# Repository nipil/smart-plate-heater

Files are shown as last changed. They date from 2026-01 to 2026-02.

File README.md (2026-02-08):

# smart-plate-heater

A weight-based, smart plate heater for ease of use and safety

- The posh wooden plate that the user sees !

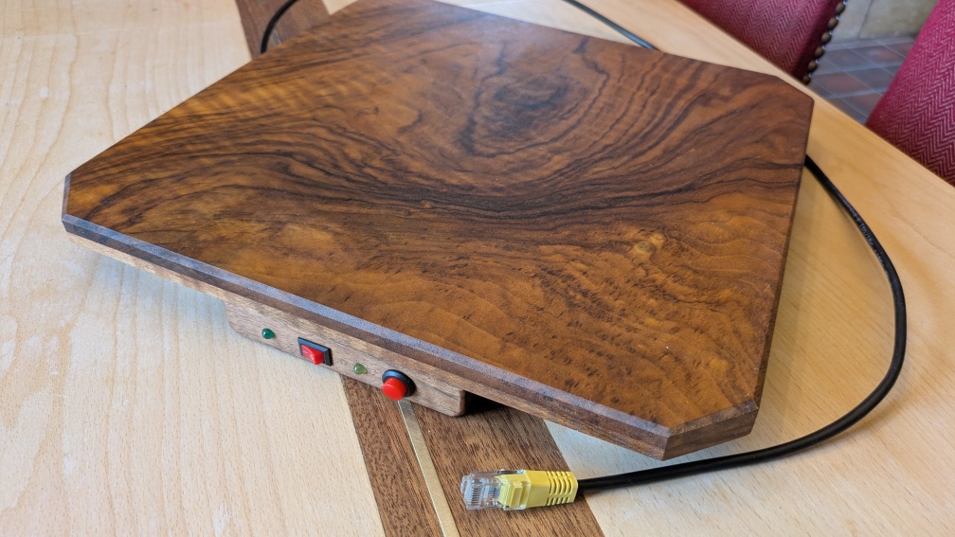
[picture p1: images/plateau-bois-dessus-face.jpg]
nice plateau


- The back "measuring foot"
  - holding all the wieght in a 3-points-of-contact setup
  - maximum 5kg vertically on the back, so an average of 10kg in center
  - the back feet do nothing except prevent tumbling

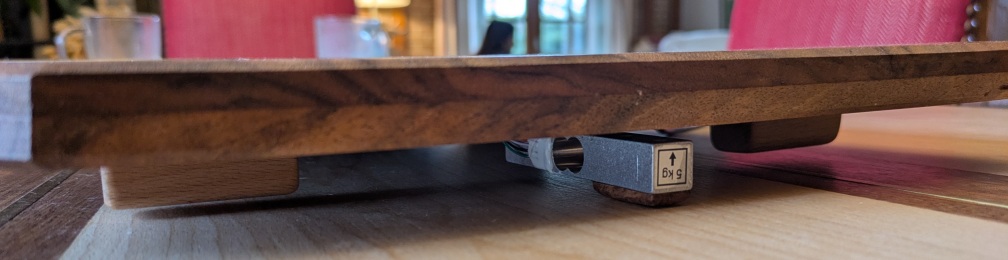
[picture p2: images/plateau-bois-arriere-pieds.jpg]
measuring foot


- due to the sensitivity of the voltages used for measuring using a strain gauge, the pre-processing must be done locally... plus the panel can be done locally too and everything fits in the 8 wires of the network cable

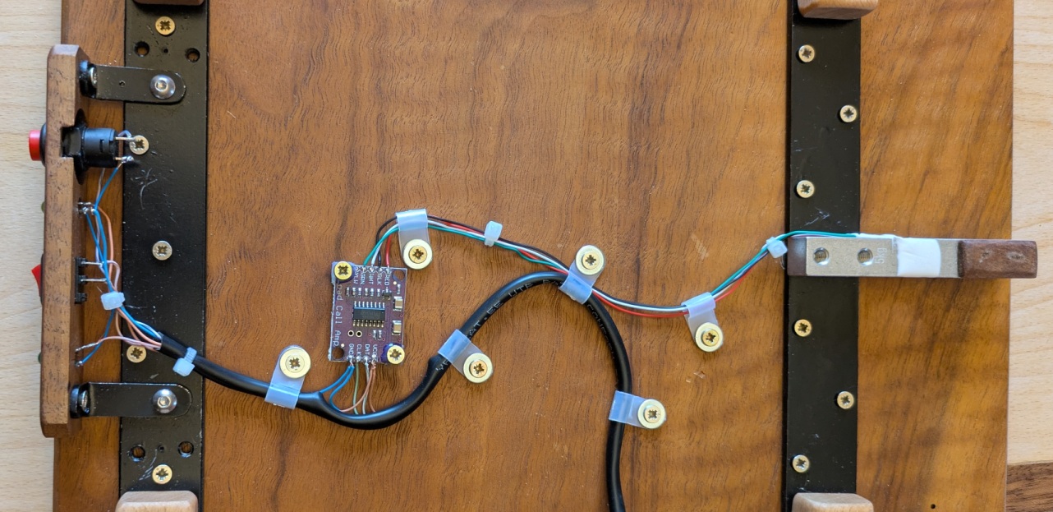
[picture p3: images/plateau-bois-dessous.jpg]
the innards


The target "perfboard pcb", with only 3 additional wires (solid core, 26 AWG, ptfe isolated wires)

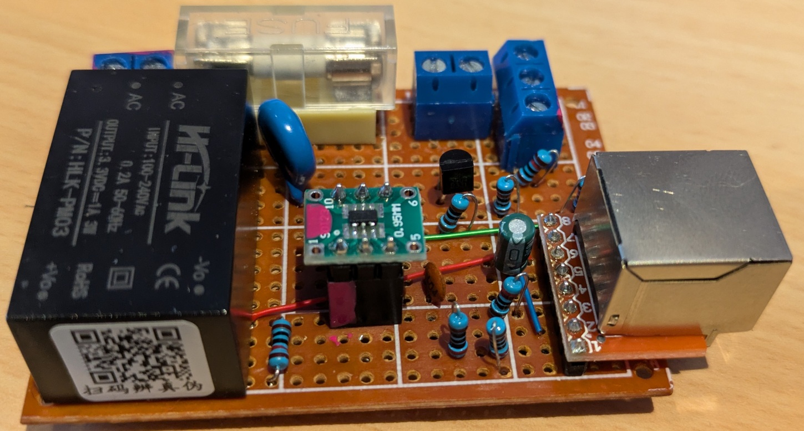
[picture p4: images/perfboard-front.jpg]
perfboard front


Only 3 shrink fit insulation patches, where i forgot to make multi-level "manhattan-style" routing

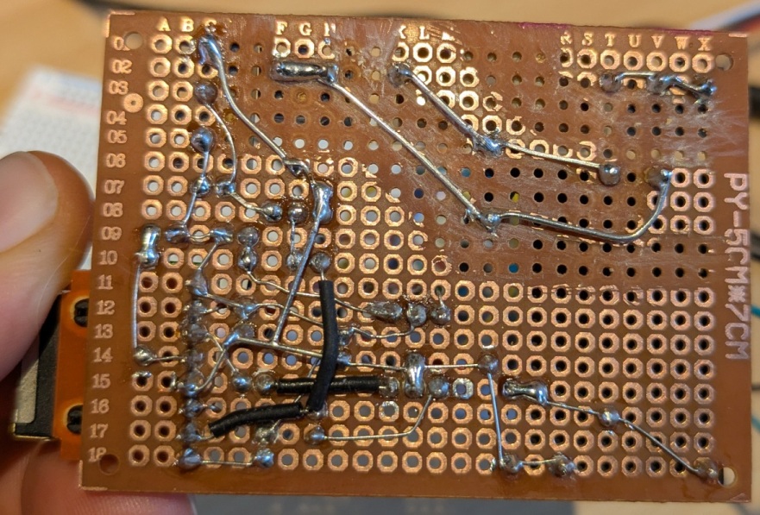
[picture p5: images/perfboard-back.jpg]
perfboard back


Everything fits in a 80x80 mm derivation box, even if it is crowded. And i can still easily take the microcontroller out, for in-situ calibration with another "debugging" MCU, and re-program the "target" MCU before sticking it back in.

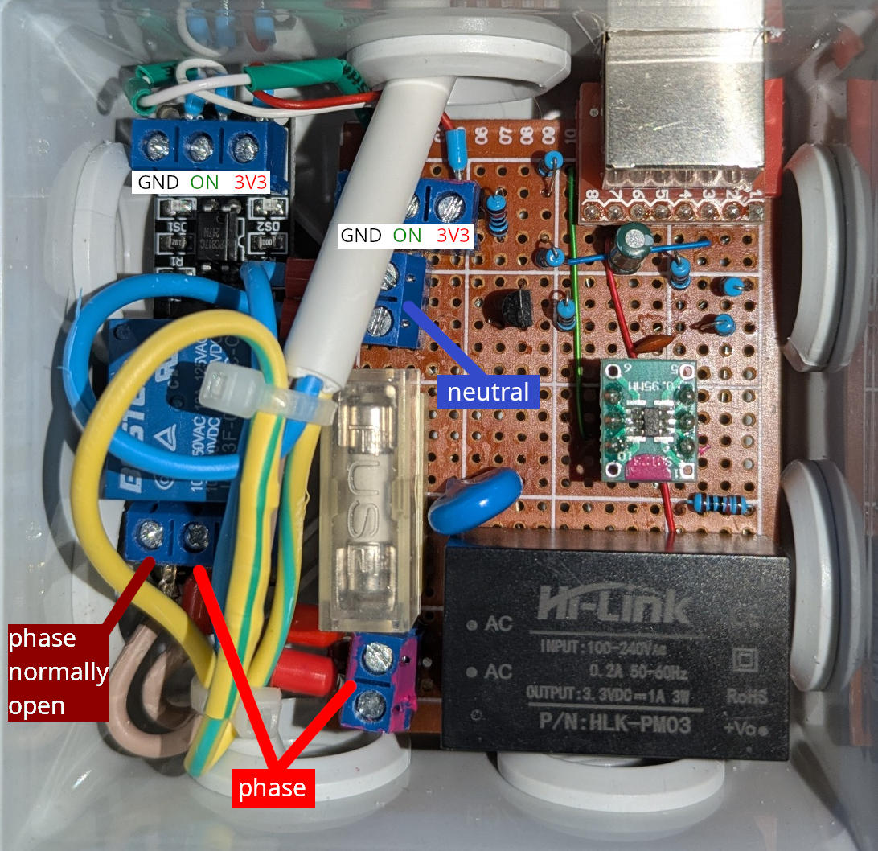
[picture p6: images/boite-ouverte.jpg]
box inside


Finally i managed to make both output exit on the same side, and the input on the opposite side, which is pretty neat.

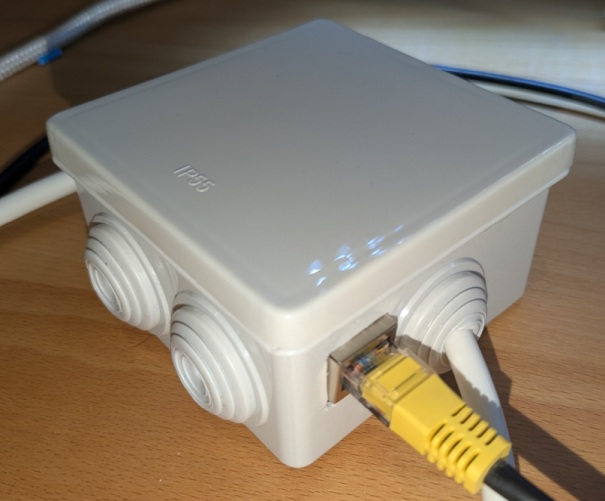
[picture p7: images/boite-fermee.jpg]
box outside


## Schematic and "perfboard" PCB

The way the main board works and AC safety is done in the derivation box

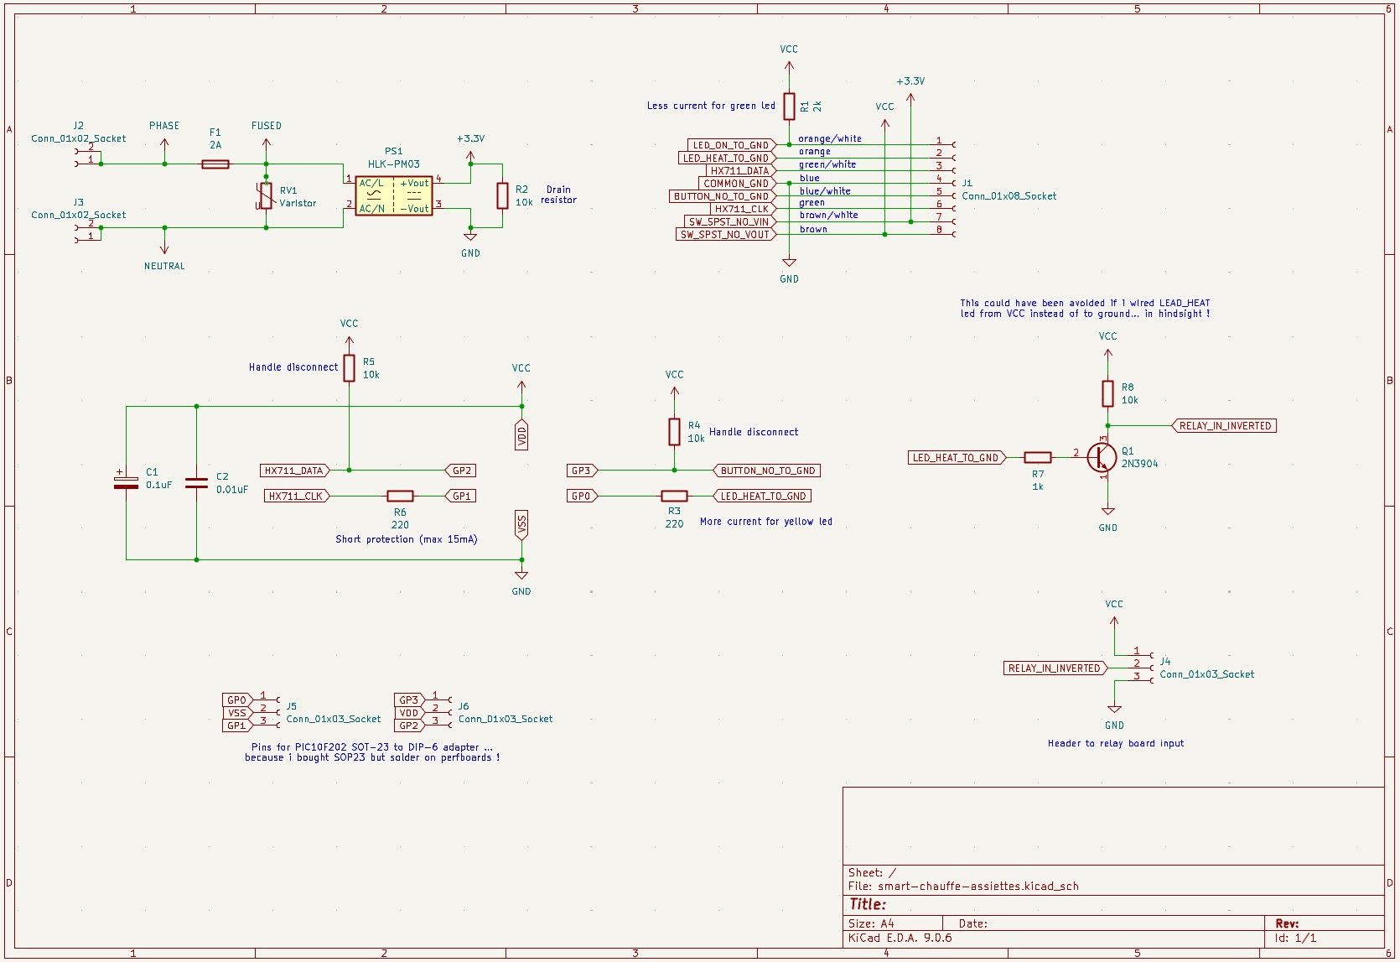
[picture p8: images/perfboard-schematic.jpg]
perfboard schematic


I always prepare my perfboard routing on a appropriately sized PCB

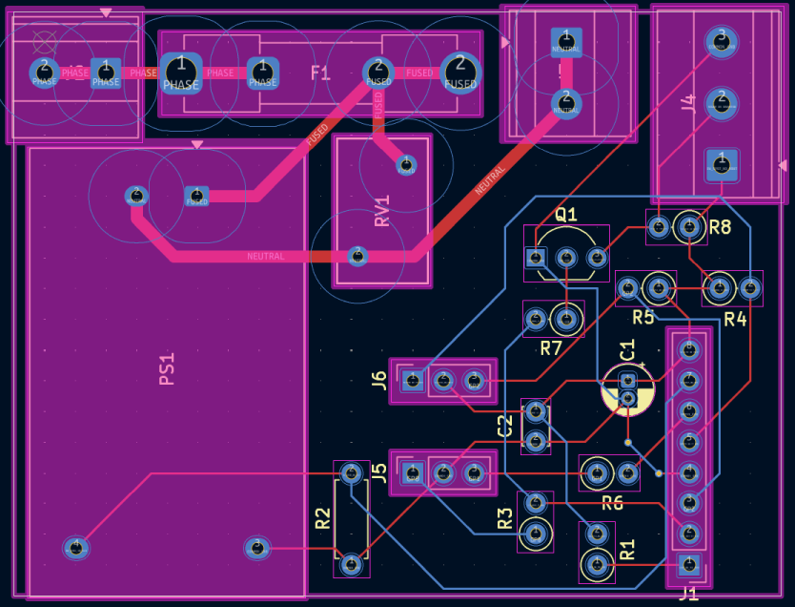
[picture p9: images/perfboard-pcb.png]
perfboard pcb


The way the appliance and user panel is wired

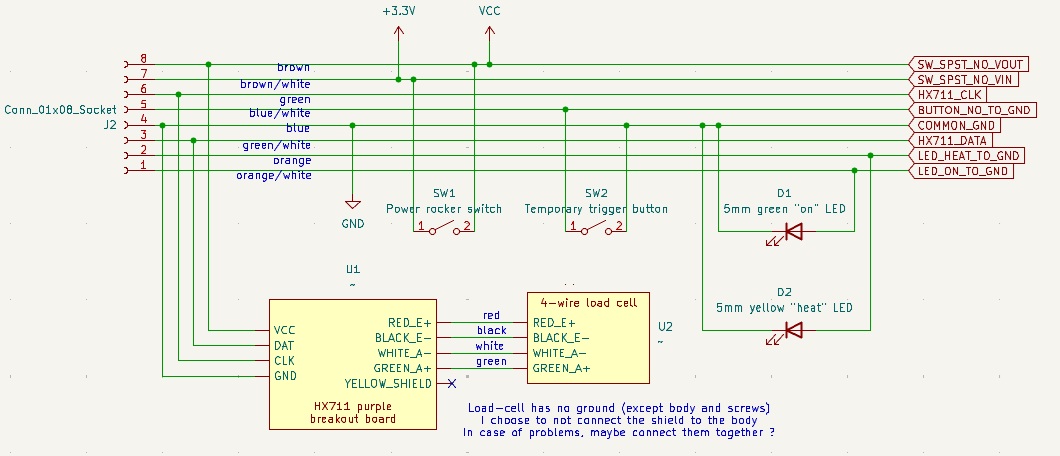
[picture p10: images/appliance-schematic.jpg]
appliance schematic


## Hardware

Target board on perfboard (uses 8mA@3V3 at idle and 80ma@3V3 when relay is on)

- PIC 10F200-family microcontroller (here a 202 in SOP-23 a DIP breakout board) from rs-online.com

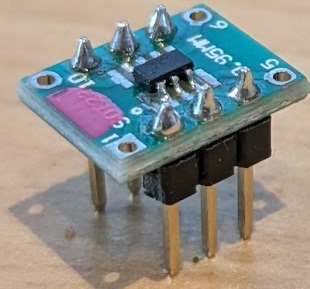
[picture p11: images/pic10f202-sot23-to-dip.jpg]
PIC 10F20x


- 500mA 5x20 fuse and fuse holder (oversized, the whole thing draws less than 0.35 W at full load)

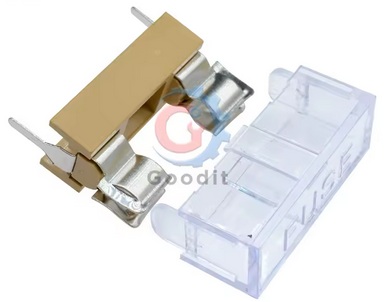
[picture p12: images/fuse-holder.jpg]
Fuse holder


- varistor 10D561K (transient voltage suppressor TVS) ot protect the circuit from grid surges

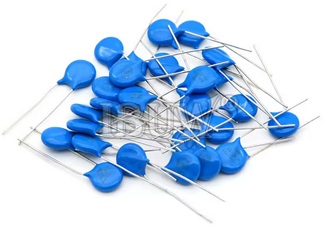
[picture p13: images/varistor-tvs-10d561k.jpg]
Varistor


- HLK-PM03 3W 240VAC to 3.3VDC converter (isolated)

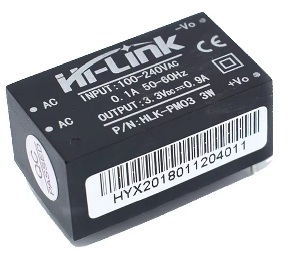
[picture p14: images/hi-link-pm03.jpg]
HLK-PM03 AC to DC converter


- HX711 breakout board (purple with holes for fixturing

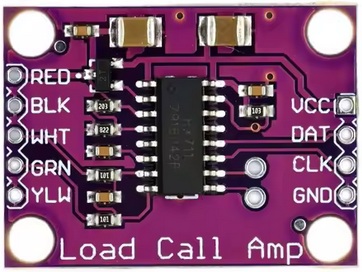
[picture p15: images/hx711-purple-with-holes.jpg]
HX711 differential ADC for strain gauges


- Beam-type load cell (maximum 5KG)

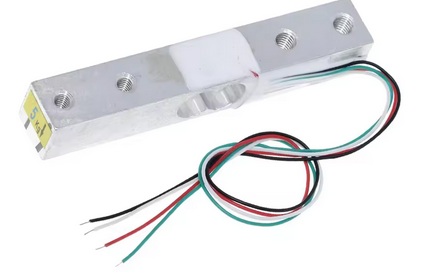
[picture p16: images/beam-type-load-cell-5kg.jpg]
Beam load cell 5KG


- 3.3V relay board (active low, floating high)

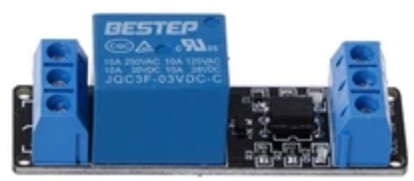
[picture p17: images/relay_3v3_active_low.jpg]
3.3V relay board


- network port breakout board, and a network cable to cut

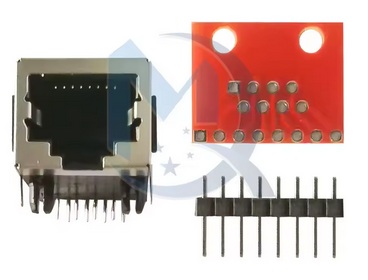
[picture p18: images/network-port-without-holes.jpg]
Network socket on a breakout board


- normally open temporary button, single pole single throw (SPST) rocker switch...
- screw terminals, 1/4W resistors, 5mm LED, headers,dc caps, 2N3904 NPN transitor...

For prototyping

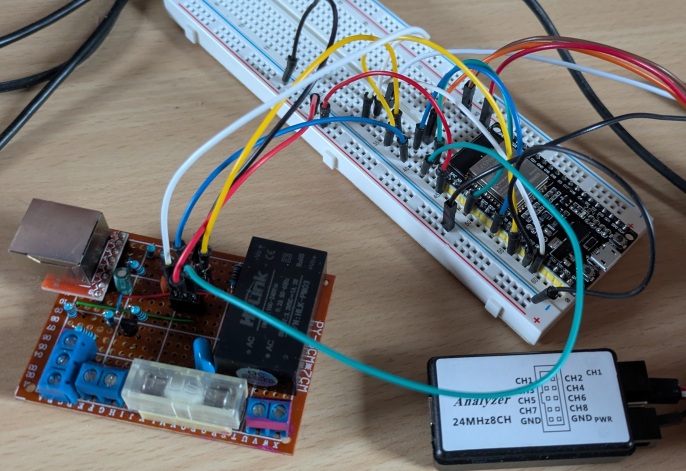
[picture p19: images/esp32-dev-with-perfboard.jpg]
dev prototyping


- breadboard and dupont cables
- ESP32 DevKit 38 pins

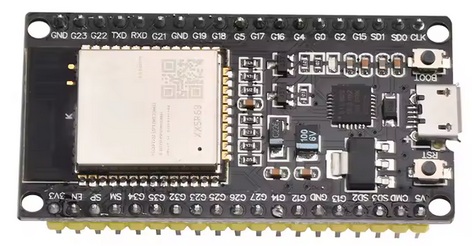
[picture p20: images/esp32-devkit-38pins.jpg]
ESP32 DevKit 38 pins


- logic analyzer (salae clone)

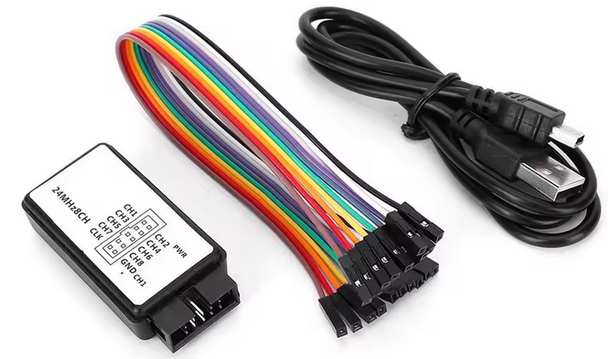
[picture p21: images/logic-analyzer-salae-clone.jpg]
Logic analyzer


Real wafeforms results in PulseView software from ESP prototype

- Macro waveforms to see sampling rate of HX711 breakout board (1 sample per 0.4 second = 2.5 Hz)

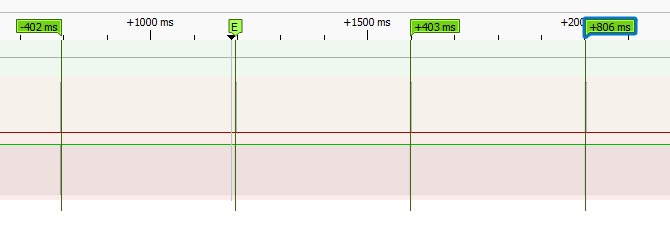
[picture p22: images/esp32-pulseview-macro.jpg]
waveforms macro view


- Micro waveforms to check the clock and data timings (data transfer time is 115 micro-seconds)

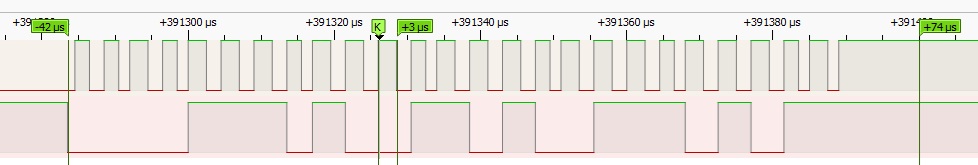
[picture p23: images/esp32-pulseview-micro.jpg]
waveforms micro view


## Pinouts

Using a PIC10F202 as microcontroller

Target perfboard using PIC10F202 SOT-23-to-DIP pinout

    PIN 1 = GP0 = OUT_HEAT  PIN 6 = GP3 = IN_BUTTON
    PIN 2 = VSS (-)         PIN 5 = VDD (+)
    PIN 3 = GP1 = OUT_CLK   PIN 4 = GP2 = IN_DATA

Arduino prototype on ESP32 DevKit pinout

    G14 = OUT_HEAT
    G25 = OUT_CLOCK
    G13 = IN_DATA
    G34 = IN_BUTTON

## kicad folder

Design for electronics and target solderboard in a box

## mplab.x folder

PIC IDE, and C code built with XC8 compiler to generate HEX file

- [Pre-compiled HEX file for a PIC10F202 microcontroller](mplab.X/pic10f202-production.hex)
- which you can program using my homemade [Arduino-UNO-based simple pic programmer](https://github.com/nipil/arduino-simple-pic-programmer)

### Debugging

Go to `Tools/Options/Embedded`

- debug reset `reset vector`
- debug startup `halt at reset vector`
- activate stimulus (*.scl) file
- use simulator to debug

### Chip fuses

Go to `Window/Target Memory View/Configuration bits`

- disable MCLRE to be able to use GP3

## arduino-esp-prototype-software folder

This is an archived folder for an arduino framework, ESP32-devboard-based prototype

Achieved goals :

- verify that everything works on 3.3V
- discover raw values for "empty" aparatus
- discover raw values for "edge" beam strain gage
- discover effect of the weight of the cable (!)
- discover the "one kilogram on center" desired threshold
- verify light / transistor / relay working when desired
- verify values upon cable disconnection
- verify disconnection disabling
- verify negative/zero HX711 values disabling
- verify reset conditions disabling
- verify heat triggering by button when above threshold
- verify heat disabling when going under threshold

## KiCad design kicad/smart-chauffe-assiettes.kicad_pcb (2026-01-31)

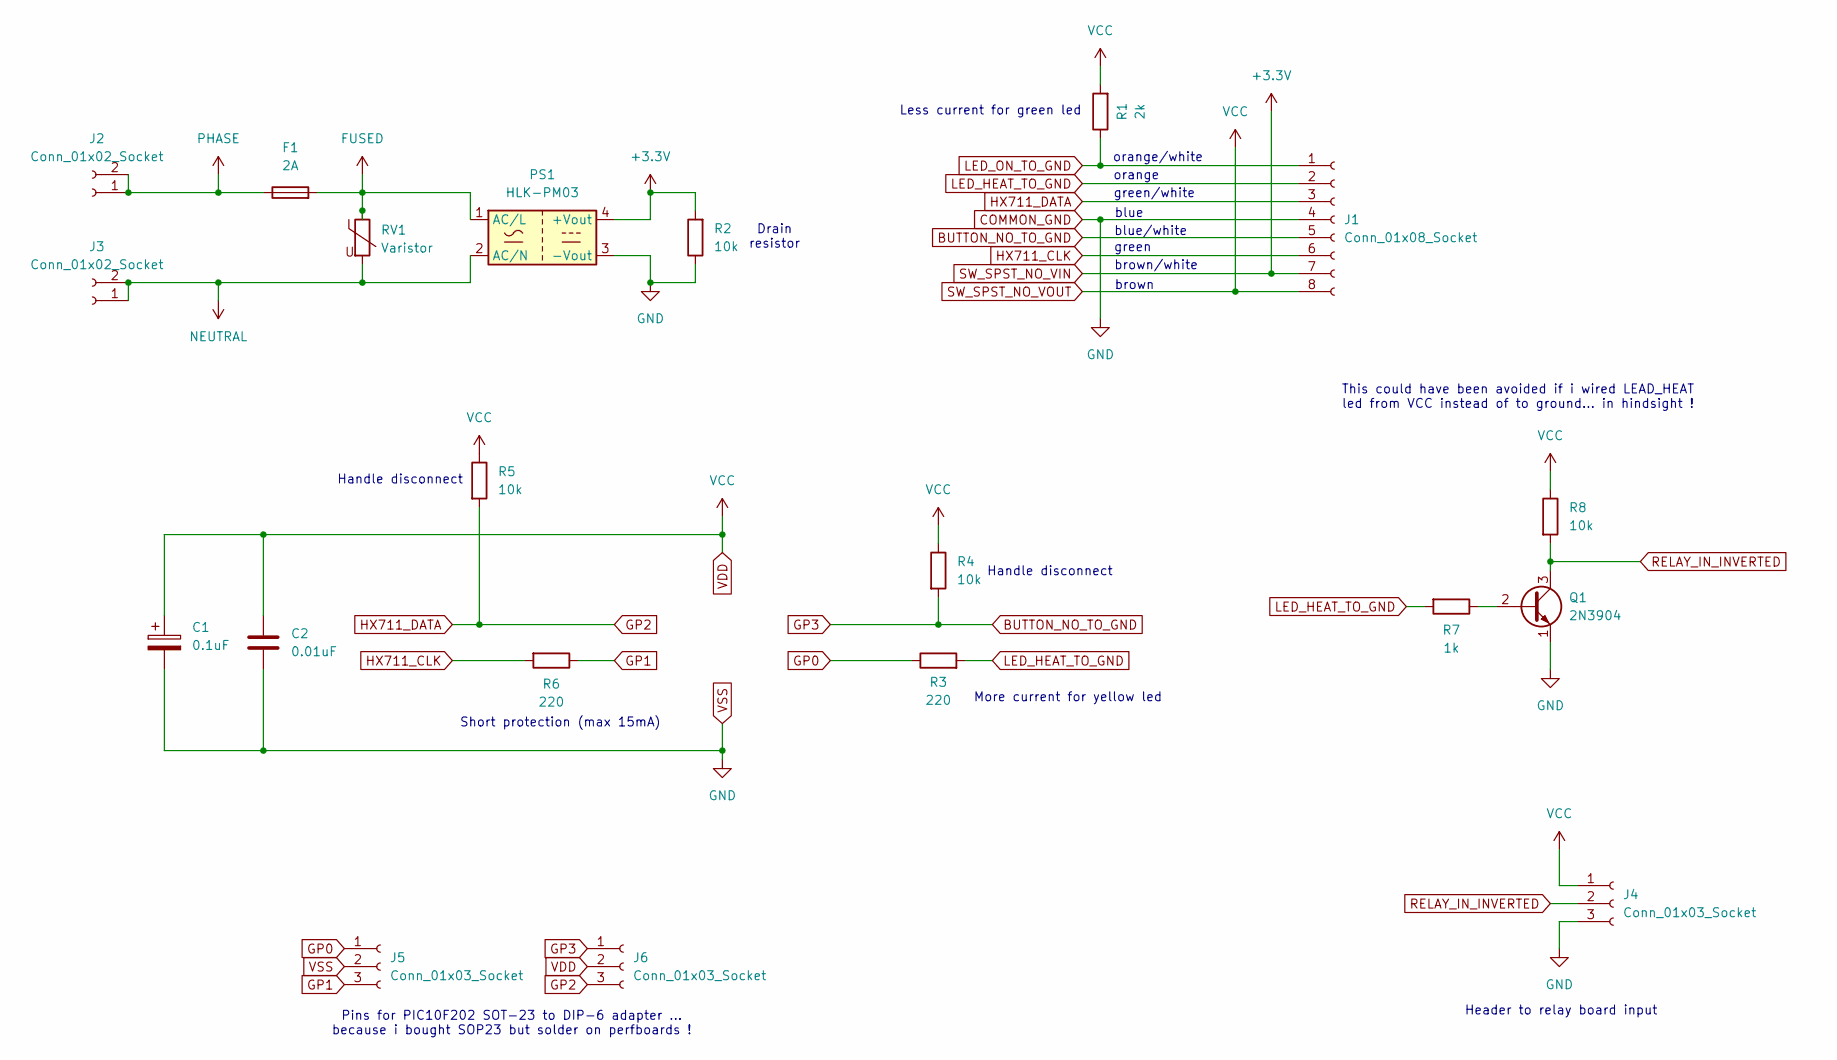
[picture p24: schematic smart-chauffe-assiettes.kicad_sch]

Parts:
C1: 0.1uF; CP_Radial_D4.0mm_P1.50mm
C2: 0.01uF; C_Disc_D3.0mm_W2.0mm_P2.50mm
F1: 2A; Fuseholder_Clip-5x20mm_Keystone_3518P_Inline_P23.11x6.76mm_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
J1: Conn_01x08_Socket; PinHeader_1x08_P2.54mm_Vertical
J2, J3: Conn_01x02_Socket; TerminalBlock_Phoenix_MKDS-1,5-2-5.08_1x02_P5.08mm_Horizont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
J4: Conn_01x03_Socket; TerminalBlock_Phoenix_MKDS-1,5-3-5.08_1x03_P5.08mm_Horizont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
J5, J6: Conn_01x03_Socket; PinSocket_1x03_P2.54mm_Vertical
PS1: HLK-PM03; Converter_ACDC_Hi-Link_HLK-PMxx
Q1: 2N3904; TO-92_Inline_Wide
R1: 2k; R_Axial_DIN0207_L6.3mm_D2.5mm_P2.54mm_Vertical
R2: 10k; R_Axial_DIN0207_L6.3mm_D2.5mm_P7.62mm_Horizontal
R3, R6: 220; R_Axial_DIN0207_L6.3mm_D2.5mm_P2.54mm_Vertical
R4, R5, R8: 10k; R_Axial_DIN0207_L6.3mm_D2.5mm_P2.54mm_Vertical
R7: 1k; R_Axial_DIN0207_L6.3mm_D2.5mm_P2.54mm_Vertical
RV1: Varistor; RV_Disc_D12mm_W7.5mm_P7.5mm

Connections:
BUTTON_NO_TO_GND: J1.5, J6.1, R4.2
COMMON_GND: C1.2, C2.2, J1.4, J4.3, J5.2, PS1.3 (-Vout), Q1.1 (E), R2.1
FUSED: F1.2, PS1.1 (AC/L), RV1.1
GP0: J5.1, R3.1
GP1: J5.3, R6.1
GP2: J1.3, J6.3, R5.2
HX711_CLK: J1.6, R6.2
LED_HEAT_TO_GND: J1.2, R3.2, R7.2
LED_ON_TO_GND: J1.1, R1.1
NEUTRAL: J3.1, J3.2, PS1.2 (AC/N), RV1.2
unnamed: Q1.2 (B), R7.1
PHASE: F1.1, J2.1, J2.2
RELAY_IN_INVERTED: J4.2, Q1.3 (C), R8.2
SW_SPST_NO_VIN: J1.7, PS1.4 (+Vout), R2.2
SW_SPST_NO_VOUT: C1.1, C2.1, J1.8, J4.1, J6.2, R1.2, R4.1, R5.1, R8.1

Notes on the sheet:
brown
Less current for green led
Short protection (max 15mA)
blue
Drain resistor
More current for yellow led
Handle disconnect
Pins for PIC10F202 SOT-23 to DIP-6 adapter ... because i bought SOP23 but solder on perfboards !
orange
orange/white
green
brown/white
Header to relay board input
green/white
This could have been avoided if i wired LEAD_HEAT led from VCC instead of to ground... in hindsight !
blue/white

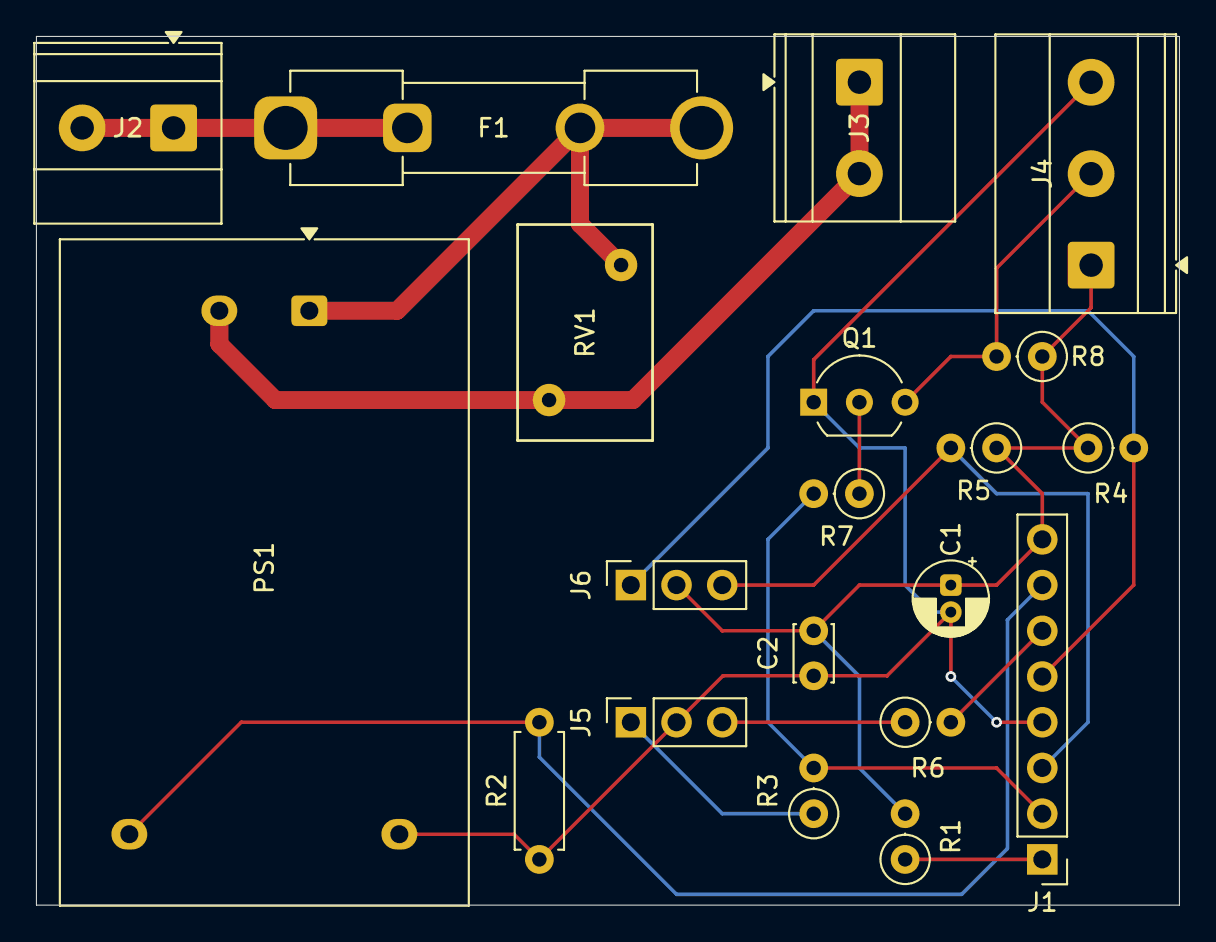
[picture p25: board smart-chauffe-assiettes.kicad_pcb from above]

Board: 2 copper layers, 63.5 x 48.3 mm, 20 parts (0 on the bottom side), 15 nets.

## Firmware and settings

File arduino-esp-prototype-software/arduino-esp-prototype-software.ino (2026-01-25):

#define MCU_ESP

#ifdef MCU_ESP
// esp devkit 38 pins
#define SERIAL_BAUDS 115200
#define BUTTON_PIN 34
#define HEAT_PIN 14
#define HX711_DOUT_PIN 13
#define HX711_SCK_PIN 25
#else
// arduino
#define SERIAL_BAUDS 9600
#define BUTTON_PIN 5
#define HEAT_PIN 4
#define HX711_DOUT_PIN 3
#define HX711_SCK_PIN 2
#endif

// esp devkit 38 pins

#define HX711_BITS 24
#define HX711_T1_MICROS 1
#define HX711_T2_MICROS 1
#define HX711_T3_MICROS 1
#define HX711_T4_MICROS 1
#define HX711_TSLEEP_MICROS 60

#define HX711_CHANNEL_BITS_A_GAIN_128 1
#define HX711_CHANNEL_BITS_B_GAIN_32 2
#define HX711_CHANNEL_BITS_A_GAIN_64 3

#define HX711_CHANNEL_BITS HX711_CHANNEL_BITS_A_GAIN_128

uint8_t hx711_read_bit() {
  digitalWrite(HX711_SCK_PIN, HIGH);
  delayMicroseconds(max(HX711_T2_MICROS, HX711_T3_MICROS));
  uint8_t value = digitalRead(HX711_DOUT_PIN);
  digitalWrite(HX711_SCK_PIN, LOW);
  delayMicroseconds(HX711_T4_MICROS);
  return value;
}

void setup() {
  Serial.begin(SERIAL_BAUDS);
  Serial.println("https://github.com/nipil/smart-plate-heater");

  pinMode(BUTTON_PIN, INPUT);
  pinMode(HX711_DOUT_PIN, INPUT);

  pinMode(HEAT_PIN, OUTPUT);
  digitalWrite(HEAT_PIN, LOW);

  pinMode(HX711_SCK_PIN, OUTPUT);

  // disable HX711
  digitalWrite(HX711_SCK_PIN, HIGH);
  delay(1);
}

// const int32_t RAW_SELF_SUSPENDED_WEIGHT = 357882L;
const int32_t RAW_SELF_GRAVITY_WEIGHT = 646718L;
// const int32_t RAW_EDGE_312_GRAMS = 793342L;
// const int32_t RAW_EDGE_1293_GRAMS = 1216109L;
// const int32_t RAW_EDGE_2254_GRAMS = 1615611L;
// const int32_t RAW_EDGE_2566_GRAMS = 1800440L;
// const int32_t RAW_EDGE_3547_GRAMS = 2248014L;
// const int32_t RAW_EDGE_3859_GRAMS = 2383308L;
// const int32_t RAW_EDGE_4619_GRAMS = 2609744L;
const int32_t UNITS_PER_GRAM = 438L;

const int32_t RAW_THRESHOLD_ALLOW_CENTER = 850000L;

// chauffe assiette centré + cordon secteur + 2ème interrupteur = 420 grammes
// chauffe assiette centré + cordon secteur + 2ème interrupteur + cable réseau = 450 grammes
// chauffe assiette centré + cordon secteur + cable réseau = 390 grammes
// 1130600 = bouteille 1293 g
// 5157735 = acier 4619 g

void loop() {

  // enable HX711
  digitalWrite(HX711_SCK_PIN, LOW);
  while (digitalRead(HX711_DOUT_PIN) == HIGH) {
    delayMicroseconds(1);
  }

  int32_t raw_value = 0;
  for (uint8_t i = 0; i < HX711_BITS; i++) {
    uint8_t bit_value = hx711_read_bit();
    raw_value = (raw_value << 1) | bit_value;
  }

  for (uint8_t i = 0; i < HX711_CHANNEL_BITS; i++) {
    hx711_read_bit();
  }

  // disable HX711
  digitalWrite(HX711_SCK_PIN, HIGH);
  delay(1);

  if (raw_value > 0x007FFFFF) {
    raw_value |= 0xFF800000;
  }

  if (raw_value <= 0) {
    // handle disconnections between modules
    digitalWrite(HEAT_PIN, LOW);
    delay(100);
    return;
  }

  // if under threshold, stop heating
  if (raw_value < RAW_THRESHOLD_ALLOW_CENTER) {
    digitalWrite(HEAT_PIN, LOW);
  } else {
    // if over threshold, check button
    if (digitalRead(BUTTON_PIN) == LOW) {
      digitalWrite(HEAT_PIN, HIGH);
      Serial.println("button");
    }
  }

  Serial.print(raw_value);
  Serial.print(" ");
  raw_value -= RAW_SELF_GRAVITY_WEIGHT;
  Serial.print(raw_value);
  Serial.print(" ");
  raw_value /= UNITS_PER_GRAM;
  Serial.println(raw_value);
}

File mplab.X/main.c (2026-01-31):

/* 
 * File:   main.c
 * Author: nipil
 *
 * Created on 17 janvier 2026, 22:03
 */

// PIC10F202 Configuration Bit Settings

// 'C' source line config statements

// CONFIG
#pragma config WDTE = OFF       // Watchdog Timer (WDT disabled)
#pragma config CP = OFF         // Code Protect (Code protection off)
#pragma config MCLRE = OFF      // Master Clear Enable (GP3/MCLR pin fuction is digital I/O, MCLR internally tied to VDD)

#include <xc.h>

// Calibration done using an arduino with serial output
// const int32_t RAW_SELF_SUSPENDED_WEIGHT = 357882L;
// const int32_t RAW_SELF_GRAVITY_WEIGHT = 646718L;
// const int32_t RAW_EDGE_312_GRAMS = 793342L;
// const int32_t RAW_EDGE_1293_GRAMS = 1216109L;
// const int32_t RAW_EDGE_2254_GRAMS = 1615611L;
// const int32_t RAW_EDGE_2566_GRAMS = 1800440L;
// const int32_t RAW_EDGE_3547_GRAMS = 2248014L;
// const int32_t RAW_EDGE_3859_GRAMS = 2383308L;
// const int32_t RAW_EDGE_4619_GRAMS = 2609744L;
// const int32_t UNITS_PER_GRAM = 438L;

// in this application we only care for the 16 most significant bits
#define RAW_THRESHOLD_ALLOW_CENTER (900000L >> 8)
#define RAW_RECODED_THRESHOLD_DISABLE_UNDEVALUE (21000L >> 8)

// PINS
// GPO / output / HEAT_LED_AND_INVERTED_RELAY
// GP1 / output / HX711 / PD_SCK
// GP2 / input / HX711 / DOUT
// GP3 / input / button (not debounced)

// HX711 : after reset channel is A with gain 128
// HX711 output is a 24 bits **signed** int
// output is a 2's complement value
// from min 0x800000 to max 0x7FFFFF

// XC8 user's manual, section "Integer Data Types" :
//   All integer values are represented in little-endian format
//   with the Least Significant Byte (LSB) at the lower address

typedef union {
    // by reading 24 bits first in uint8 #3, then #2, then #1
    uint8_t as_uint8[4];
    // we then can read the most significant bits in int16 #1
    int16_t as_int16[2];
} HX711_VALUE;

void main(void) {

    // Allow using GP2 as GPIO (disable T0CS)
    OPTION = 0xFF & ~T0CS;

    // define HEAT OUTPUT (before TRIS ? need pull-down anyway)
    GPIObits.GP0 = 0;

    // define HX711 CLOCK OUTPUT (before TRIS ? need pull-up anyway)
    GPIObits.GP1 = 1;

    // use GP3 and GP2 as input, GP1 and GP0 as output
    TRIS = 0b1100;

    // define HEAT OUTPUT (after TRIS ? then glitched to whatever was set)
    GPIObits.GP0 = 0;

    // define HX711 CLOCK OUTPUT (after TRIS ? then glitched to whatever was set)
    GPIObits.GP1 = 1;

    // make sure HX711 goes to sleep
    _delay(100);

    // recorded value on threshold
    int16_t recorded_value = 0;

    while (1) {
        // less opcodes if using 8 or 16 bits than 32 bits
        HX711_VALUE values;
        values.as_int16[0] = 0;
        values.as_int16[1] = 0;

        // when PD_SCK is LOW, chip is active
        GPIObits.GP1 = 0;

        // wait for data ready (T1)
        while (GPIObits.GP2);

        // it is 2x faster to process 24 bits as 3 times 8 bits
        // than to use an int32, *AND* it prevents the HX711
        // from going to sleep if clock is high during +60us
        // IMPORTANT : HX711 gives MSB bit first
        for (uint8_t j = 3; j > 0; j--) {
            for (uint8_t i = 0; i < 8; i++) {

                // clock rise
                GPIObits.GP1 = 1;
                // wait for data ready (T2)
                _delay(1);

                // read data bit and append from low side
                values.as_uint8[j] <<= 1;
                values.as_uint8[j] |= GPIObits.GP2;

                // wait high (T3)
                _delay(1);
                // clock fall
                GPIObits.GP1 = 0;
                // wait low (T4)
                _delay(1);
            }
        }

        // PD_SCK should do 1-3 more cycle for next channel select
        // 1 = channel A gain 128
        // 2 = channel B gain 32
        // 3 = channel A gain 64

        // clock rise
        GPIObits.GP1 = 1;
        // wait high (T3)
        _delay(1);
        // clock fall
        GPIObits.GP1 = 0;
        // wait low (T4)
        _delay(1);

        // disable HX711
        GPIObits.GP1 = 1;

        // make sure HX711 goes to sleep
        _delay(100);

        // uint8_t stimulus_values[3] = {
        // 0x37, // 0b00110111 // MSB
        // 0xDF, // 0b11011111
        // 0xEF  // 0b11100111 // LSB
        // };

        // FIXME: process engouh bits ... or not ?

        // SAFETY: if too light at all, disable unconditionally
        if (values.as_int16[1] < RAW_THRESHOLD_ALLOW_CENTER) {
            GPIObits.GP0 = 0;
            continue;
        }

        // FUNCTION: if too light relatively to the recorded value, disable
        if (values.as_int16[1] < recorded_value) {
            GPIObits.GP0 = 0;
            recorded_value = 0;
            continue;
        }

        // enough weight present is still present

        // if button is not pressed (state high, pulled-up), stay the same
        if (GPIObits.GP3) {
            continue;
        }

        // button is pressed (state forced to low)

        // enable heat output
        GPIObits.GP0 = 1;

        // record current value for later use as a fine threshold (less opcodes if done in 2 steps)
        recorded_value = values.as_int16[1];
        recorded_value -= RAW_RECODED_THRESHOLD_DISABLE_UNDEVALUE;
    }
}

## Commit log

2026-01-21 Compare with reference weight, and (de)activate opto
2026-01-24 Added final hardware calibration : raw 24 bit values
2026-01-25 Add working ESP32 3.3v prototype validated on breadboard
2026-01-25 Add first stab at schematic
    [smart-chauffe-assiettes.kicad_pcb, smart-chauffe-assiettes.kicad_sch]
2026-01-26 Finalize schematic : inverted relay and sop23-to-dip6 adapter
    [smart-chauffe-assiettes.kicad_sch]
2026-01-26 Fix footprint for header to relay input
    [smart-chauffe-assiettes.kicad_sch]
2026-01-26 First attempt at laying out the components
    [smart-chauffe-assiettes.kicad_pcb]
2026-01-26 Add text for design info and rename power networks
    [smart-chauffe-assiettes.kicad_sch]
2026-01-26 Add custom rule for power networks
2026-01-26 First stab at routing
    [smart-chauffe-assiettes.kicad_pcb]
2026-01-28 Switch from shifting bits into an int32, to shifting into 3 uint8
2026-01-30 Rename INO file to match arduino convention
2026-01-30 Filter numerical data using kappa-sigma-median clipping
2026-01-30 Ignore traces during simulation
2026-01-31 PIC/FIX: allow restarting after lowered weight (recorded)
    [main.c]
2026-01-31 Added pinout for both boards
2026-01-31 Fix missing power trace and swap psu leads
    [smart-chauffe-assiettes.kicad_pcb, smart-chauffe-assiettes.kicad_sch]
2026-02-01 Add schematic documentation for appliance wiring (hx711/cell sym lib)
    [appliance-wiring.kicad_sch]
